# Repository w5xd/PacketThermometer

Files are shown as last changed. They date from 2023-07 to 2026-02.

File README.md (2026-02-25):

This repository documents a wireless thermometer project. 
Included are: a circuit design using Arduiono, a PCB design for the Arduino Pro Mini, an Arduino sketch. And an outdoor 3D printed enclosure.

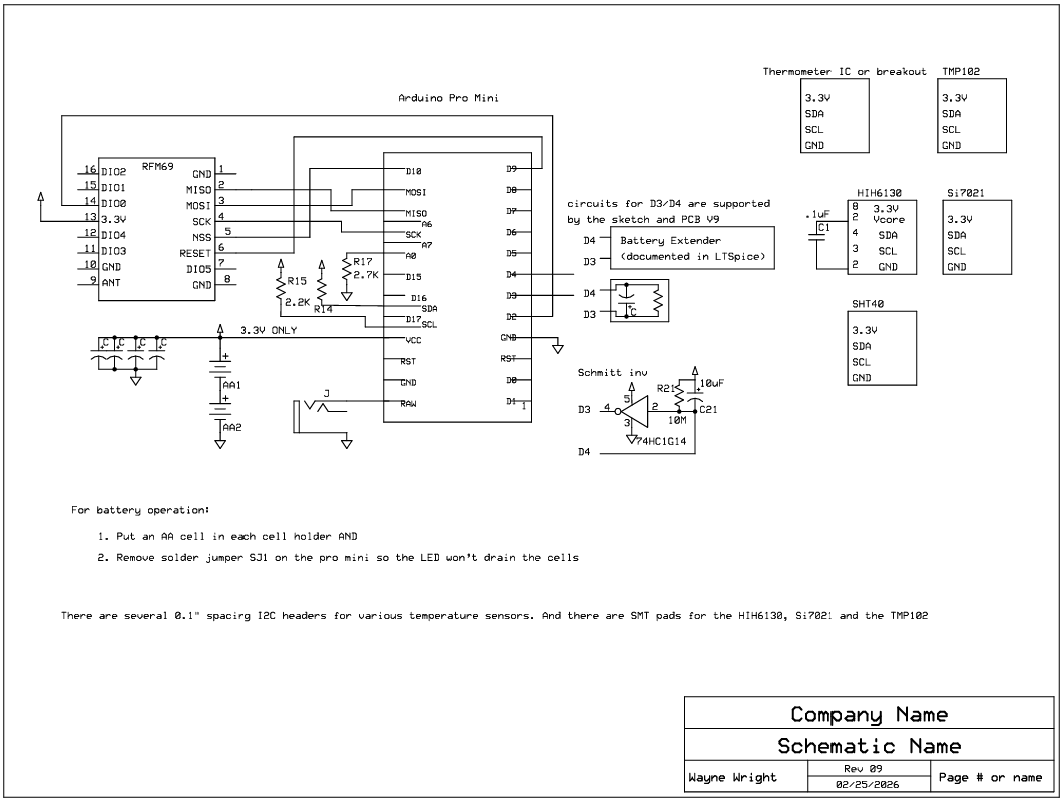
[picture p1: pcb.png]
<p align='center'></p>

The hardware configuration is the combination of the RFM69 wireless module
(<a href='https://learn.sparkfun.com/tutorials/rfm69hcw-hookup-guide'>https://learn.sparkfun.com/tutorials/rfm69hcw-hookup-guide</a>)
and any of several temperature and humidity sensors listed here.
The sensor positions on the PCB are:
<ul>

<li>TMP102. Its SMD board layout puts it at i2c address 0x49.
<li>There are headers  on the PCB for various break out temperature sensors.
The pin hookups are the same for any sensor: GND, VCC (3.3V), SDA, SCL are required.
The pin positions on the various Sparkfun breakout boards differ, which
is why there are several hole patterns on the PCB for headers</li><a href='https://learn.sparkfun.com/tutorials/tmp102-digital-temperature-sensor-hookup-guide'>https://learn.sparkfun.com/tutorials/tmp102-digital-temperature-sensor-hookup-guide.</a>
<li>HIH6131, measures humidity as well as temperature. The PCB layout puts it at i2c 0x27.
<a href='https://www.sparkfun.com/products/11295'>HIH6130</a>
has humidity in addition to temperature, but is limited to -20C to 85C.</li>
<li>Si7021, measures humidity and temperature. It is fixed at i2c 
address 0x40. It has a rather coarse temperature readout--about 1 degree Farenheit resolution
when set to its default 14 bit temperature digitization.
<li>SHT40. measures humdity and temperature. Address 0x44.
<li>TMP175. Temperature only. PCB leaves all address pins floating, therefore its i2c address is 0x37.

</ul>
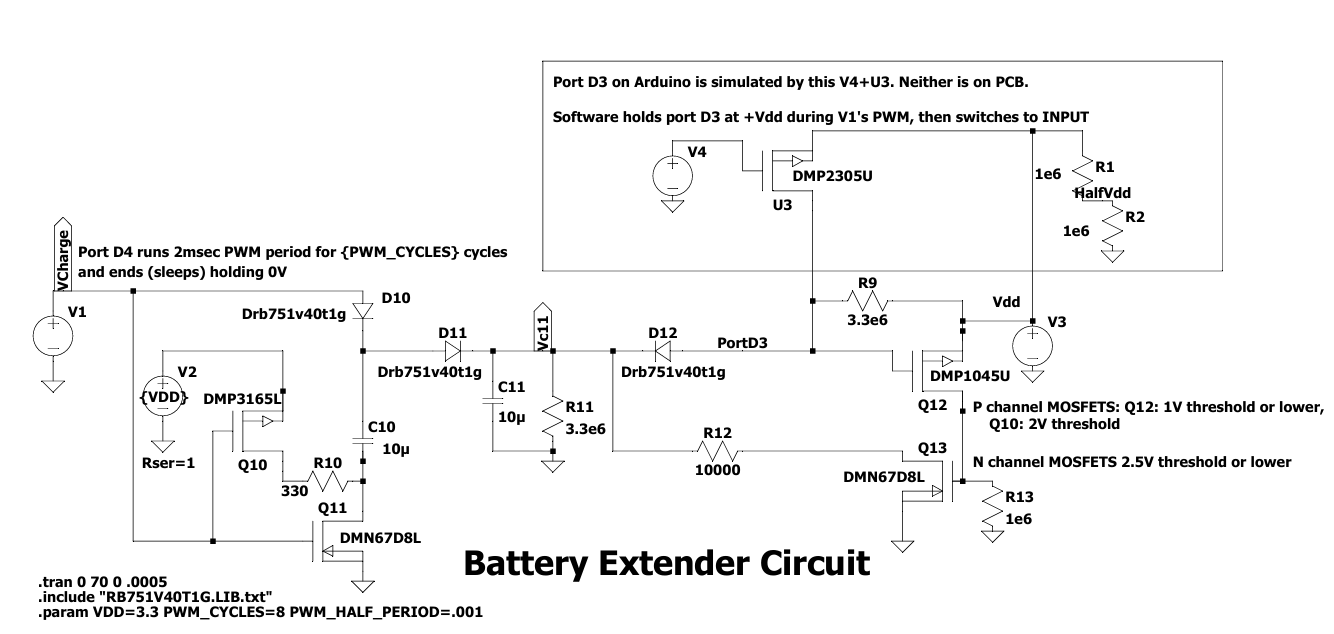
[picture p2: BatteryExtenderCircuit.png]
BatteryExtenderCircuit
<p align='center'></p>

Battery Extender

Three different circuits for implementing the long sleep time have been implemented. The original design, implemented
on PCB05 and earlier, is simply a parallel RC on the INT pin (D3 on the Arduino). Those components can be
chosen for an RC delay of as much as 100 seconds (10M times 10uF). That slow moving input stays close to
Vcc/2 for an extended period, which in turn causes the Atmega328 to draw up to about 
500uA above its minimal
sleep current for an extended length of time (See the Atmega328P specifications.) PCB06 places an inverting 74HC1G14 schmitt trigger 
to handle the slow-moving RC input. It has a lower current draw near Vcc/2, peaking below 300 uA.
PCB8 implements the MOSFET Battery Extender. PCB9 has PCB placements for all the above. The sketch
must be compiled for the hardware on the PCB, of course. And there is an option in the ino file for "none of the above"
which uses the CPU's Timer2 circuit and constant current draw of about 200uA.

The logic family of the schmitt trigger is important. The
74AHC1G14 draws about triple the current of the 74HC1G14 per their datasheets regarding slow moving inputs through Vcc/2. 
See the file <code>power&nbsp;supply&nbsp;current&nbsp;during&nbsp;RC&nbsp;decay.pdf</code> for actual measurements on a PCB version 6 with the CPU and TMP175 but
no RFM69.

REV08 and later have the Battery Extender Circuit. 
The Battery Extender eliminates the long period of excess current draw by 
accelerating the decay through Vcc/2. The circuit depends on a 
p-channel MOSFET with a low
gate threshold. The nominal threshold of the specified DMP1045U part
is -700mV, well outside of -Vcc/2. That MOSFET, Q12, turns on when the RC circuit at C11, R11 discharges that far
below Vcc. This in turn activates Q13 to quickly truncate the R11/C11 decay through R12, which then
crosses Vcc/2 in a few milliseconds. The other pair of MOSFETs, Q10 and Q11, implements a charge pump so that the
RC circuit discharges from as much as double Vcc (about 6V) to get a much longer time 
delay than is feasible without it.
The capacitors in the Battery Extender circuit can be identical, but must be ceramic 
(for very low leakage current compared to polarized capacitors.) Here is the modeled 
voltage at pin D3 from the LTSpice model.

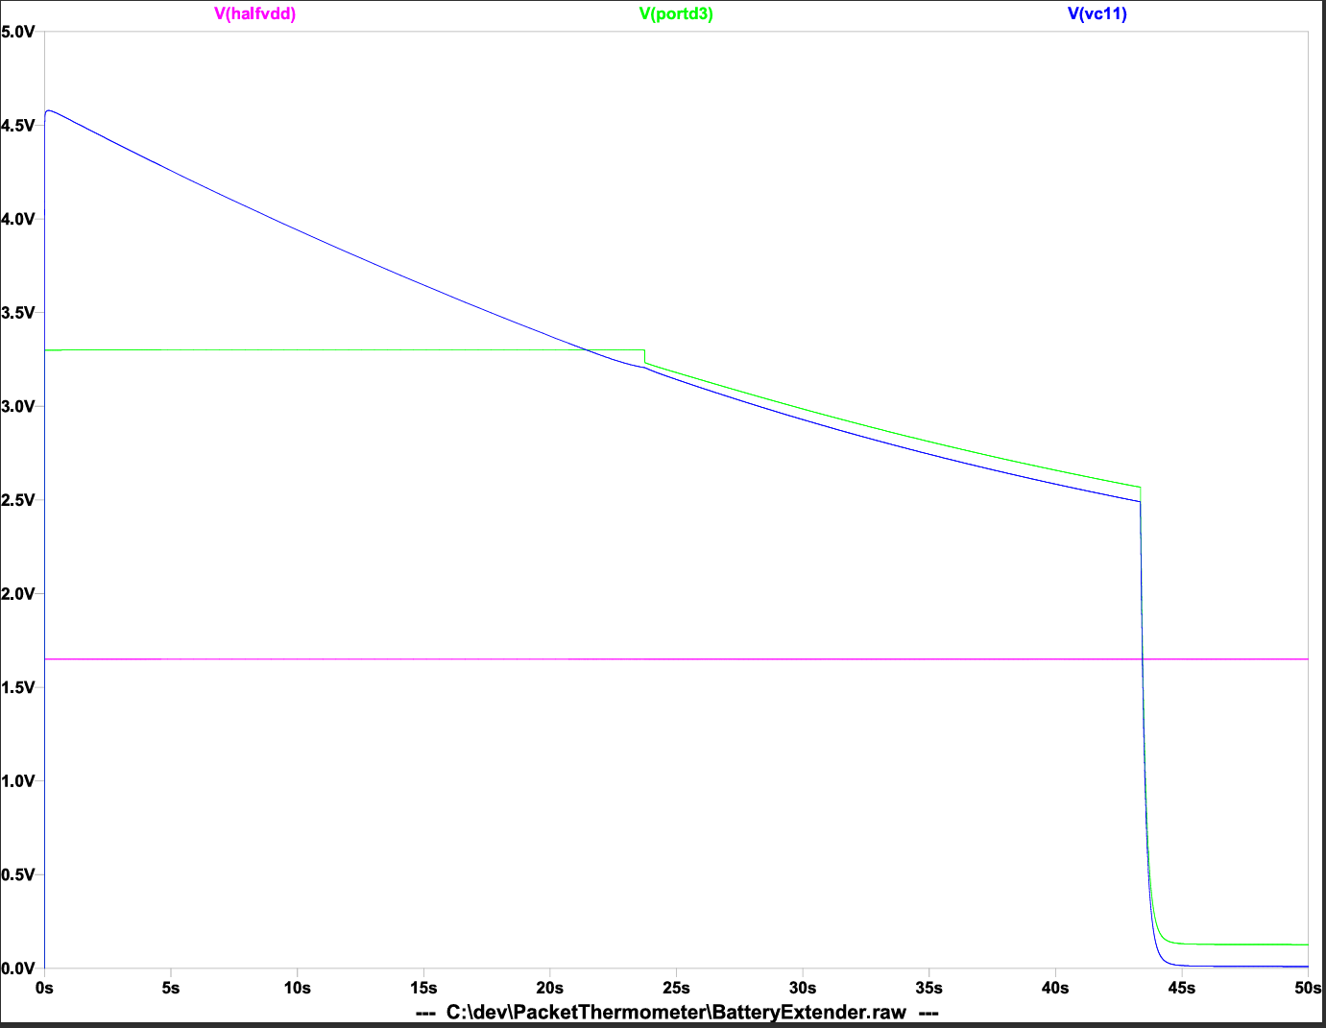
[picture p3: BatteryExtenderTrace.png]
BatteryExtenderTrace
<p align='center'></p>

Later PCB versions can be reverted to the REV05 single R and C timer by omitting all the Battery Extender components
except for  R11 and C11, along with installing a jumper in the holes provided at D12. The
appropriate #define in the ino file for REV05 must be uploaded.

PCB assembly

The parts list for building the PCB, including the Battery Extender: 
<a href='https://www.mouser.com/Tools/Project/Share?AccessID=548d5f9ecc'>
https://www.mouser.com/Tools/Project/Share?AccessID=548d5f9ecc</a>. The headers and battery holders,
and any hardware needed to mount in an enclosure are also needed.

|Quan|Item|Value|Form|
|:-|:-|:-|:-|
4|C1, C2, C3, C5|0.1µF|EIA 1206|
|3|C10, C11, C21|10µF|EIA 0805|
|1|C4|10µF|EIA 1206|
|3|D10, D11, D12|DRB751V40T1G||
|2|HIH6131, TMP175|SO8||
|1|J15|2.1 mm barrel jack PJ-202A|for power plug|
|1|Q10|DMP3165l|SOT23-3|
|2|Q11, Q13|DMN67D8L|SOT23-3|
|1|Q12|DMP1045U|SOT23-3|
|2|R9, R11|3.3M|EIA 0805|
|1|R10|330|EIA 0805|
|1|R12|10K|EIA 0805|
|1|R13|1M|EIA 0805|
|2|R14, R15|2.2K|EIA 0805|
|1|R17|2.7K|EIA 1206|
|1|R21|10M|EIA 0805|

Only one of the battery saver circuit, or the 74HC1G14 time delay circuit, can be installed.<br/>
The battery saver is R9-R13, D10-D12, Q10-Q12, C10 and C11.<br/>
The 74HC1G14 needs R21 and C21.<br/><br/>

While the PCB has multiple positions for placing temperature sensors, the sketch reports temperature
from just one of them per the #define in the ino file.
I had success baking the SMD circuits with tight clearances using the technique in this
<a href='https://www.youtube.com/watch?v=xPFujTJbUkI'>video</a>.
The Battery Extender circuit is positioned under the Pro Mini, which makes it impossible to test
if the Arduino is in place. If you are going to install the assembled PCB in the 3D printed
weather tight enclosure, the assembly only fits if you solder the Pro Mini in place with, at most,
0.100 inch headers between the Arduino and the PCB. That is, you must test the Battery Extender
before soldering the Pro Mini in place. This order of assembly is <i>required</i> for that case
of installing this PCB in the 3D printed enclosure:
<ol>
<li>Prepare an Arduino with headers that can be jumped to headers on the PCB at the Arduino
position. A 5V Arduino (like an Uno or Mega) can be used in this test step, but then you <b><i>must</i></b> omit
all the 3.3 volt parts in the following SMD baking step!
<li>Bake all the Battery Extender SMD components onto the PCB. 
<li>Install headers on the PCB that will eventually be used to mount the 3.3V Pro Mini.
<li>Upload the WirelessThermometer.ino sketch with appropriate #define's set onto the
test Arduino.
<li>Jumper the following pins between the two boards:
<ol>
<li>Ground
<li>RAW (3.3V or 5.0V)
<li>D3
<li>D4
</ol>
<li>At this point the thermometer should successfully sleep according to the parameter SetD4PwmCount.
Set to zero, it should sleep for about 7 or 8 seconds.
SetD4PwmCount up to 255 should sleep for more than 65 seconds.
<li>If you baked a temperature sensor, it should also be printed out on the Serial port.
<li>Once the Battery Extender circuit works as predicted, the remaing top side PCB components should be
mounted <i>except</i> the Pro Mini
<li>Solder the AA cell holder(s) to the PCB bottom. In REV08 of the PCB and later, and using
the Keystone 2462 double AA holder, these last two items can be in either order.
Otherwise, you had better solder the Pro Mini last.
<li>Finally, the Pro Mini may be soldered onto the headers installed in step (3) above.
</ol>

Power options
<ul>
<li>The circuit is simple and can be haywired without a PCB. 
<li>The PCB has positions for two AA cells. It has hole configurations for
cell holders. Either a two-cell keystone 2462 holder or two one-cell keystone 2460 
holders fit. In PCB REV08 and later, the 2462 fits in either of two orientations that are 180 degrees rotated.
<li>On the Arduinio Mini Pro, 3.3V version, remove solder jumper SJ1 to disable
the on-board volatage regulator and, especially, the power drain from its LED. 
<li>Or, a PJ-202A 5.5mm x 2.1mm power jack may be installed on the PCB, which routes up to 12VDC
to the regulator on the Pro Mini. The PCB has holes to accommodate the jack on either
the PCB's top or bottom.
</ul>

SMD components of size 1206 and 0805 are easy enough to solder by hand. 
A pair of AAA lithium cells
powered one of these for 9 months (and counting) with SetDelayLoopCount 
configured such that updates occur about every 11 minutes. A different unit
configured for 5 minute updates lasted 6 months. AA cells are rated
to about twice the Amp-Hour life of the equivalent chemistry AAA cells.

A 2.7K resistor is from A0 to ground for the purpose of telemetering the battery volatage. 

The system is powered with the 2 cell battery wired to VCC (not RAW).

The required SetFrequencyBand settings are documented in RFM69.h (91 in USA). The Arduino
can be programmed through either its serial interface or the ISP pins on the PCB. But
the RFM69 configuration can only be accomplished through the Arduino's serial interface. 

Cover

The CAD directory has a 3D model for a one-piece enclosure that covers the arduino, but leaves the
battery pack exposed. And there is also a 3D model for weather tight O-Ring enclosure that 
mates the PCB holes.

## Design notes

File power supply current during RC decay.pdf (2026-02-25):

Sheet1

Power supply current measurements

Time (s) | 74AHC1G14 | 74HC1G14
10 | 0 | 0
20 | 0.2 | 10
30 | 22 | 40
40 | 80 | 85
50 | 160 | 132
60 | 240 | 180
70 | 325 | 220
80 | 420 | 260
90 | 500
100 | 570
110 | 630

uA

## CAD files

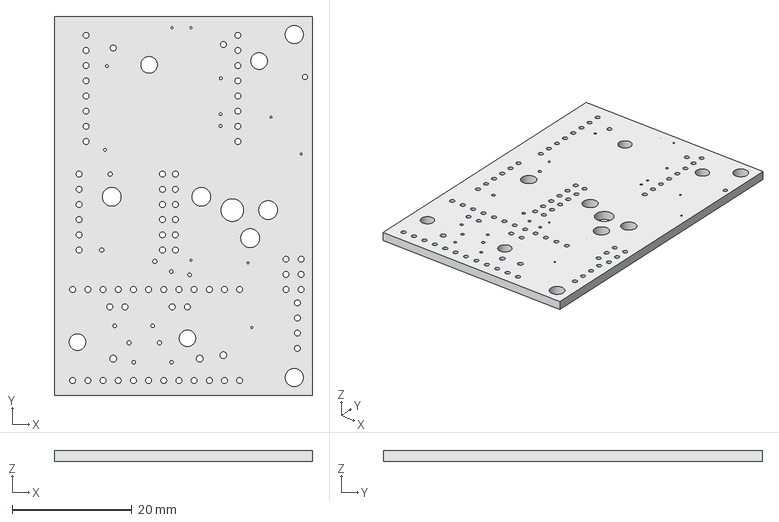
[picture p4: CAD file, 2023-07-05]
CAD/pcb-packet-thermometer.step
43.2 x 63.5 x 1.78 mm

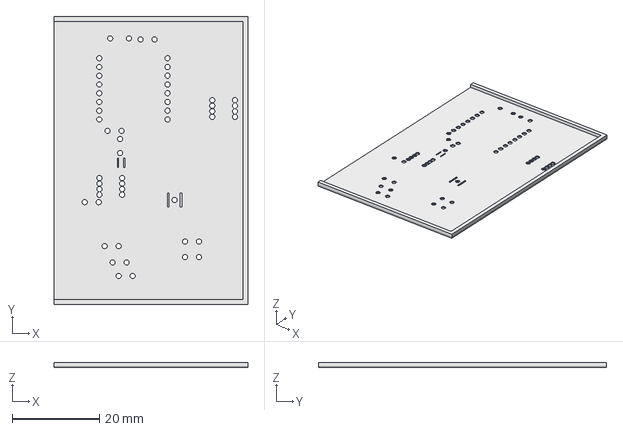
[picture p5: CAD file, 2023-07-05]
CAD/pcb-packet-thermometer-mask.step
44.4 x 65.9 x 1.20 mm

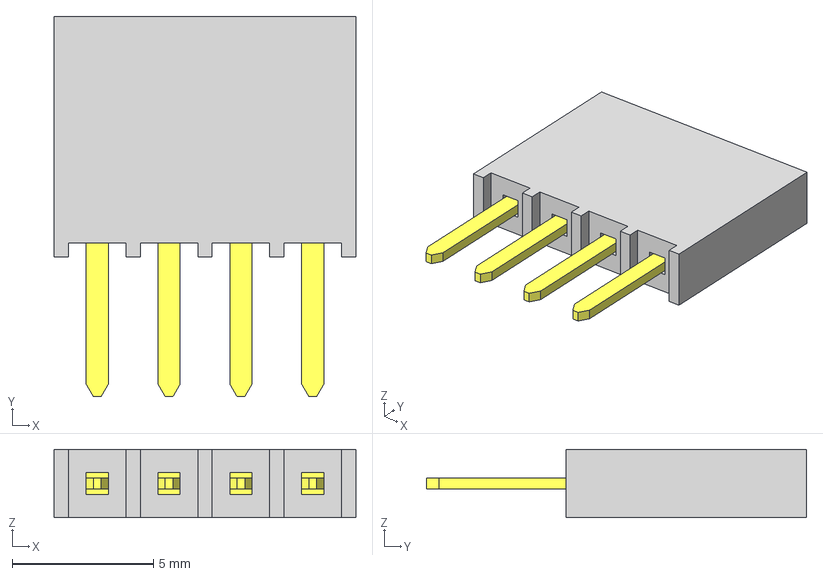
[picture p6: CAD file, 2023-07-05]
CAD/SSW-104-02-T-S.stp
10.7 x 13.4 x 2.41 mm
P2SSW-104-02-T-S
T1SSW-104-02-T-S

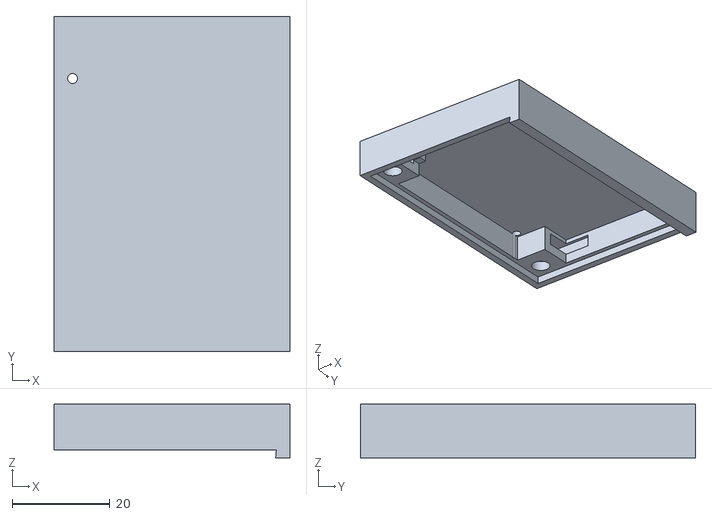
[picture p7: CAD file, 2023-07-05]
CAD/cover.stl
48.3 x 68.6 x 11.0

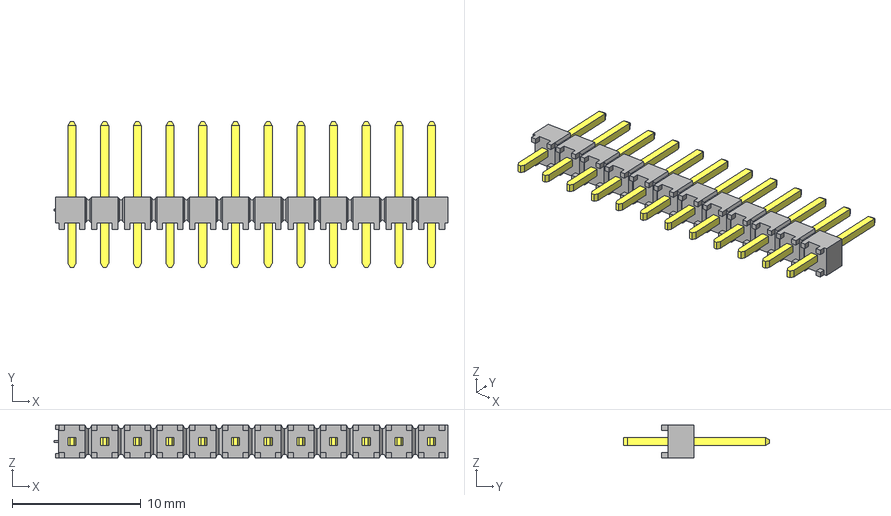
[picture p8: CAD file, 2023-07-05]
CAD/TSW-112-23-T-S.stp
30.6 x 11.3 x 2.54 mm
T-1S6-16-TSW-1-23-12-S
TSW-112-23-T-S_body

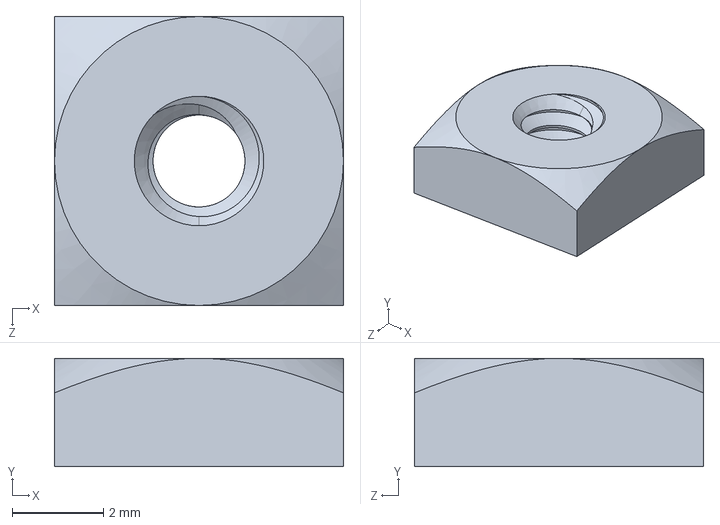
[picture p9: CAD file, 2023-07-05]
CAD/94785A511_18-8 Stainless Steel Square Nut.STEP
6.35 x 2.38 x 6.35 mm

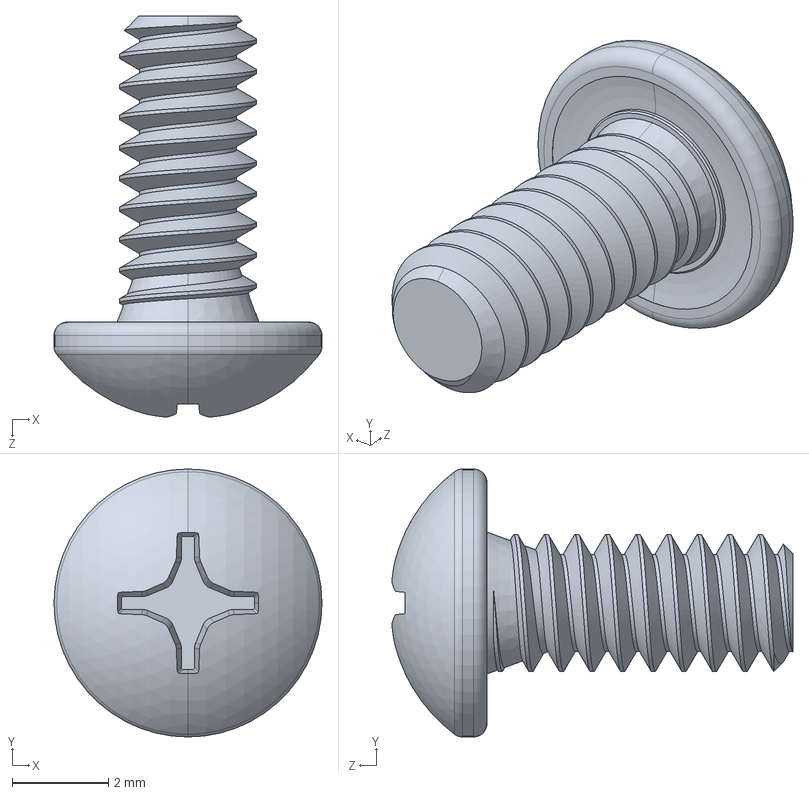
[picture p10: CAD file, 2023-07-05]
CAD/91772A106_Passivated 18-8 Stainless Steel Pan Head Phillips Screw.STEP
5.56 x 5.56 x 8.32 mm

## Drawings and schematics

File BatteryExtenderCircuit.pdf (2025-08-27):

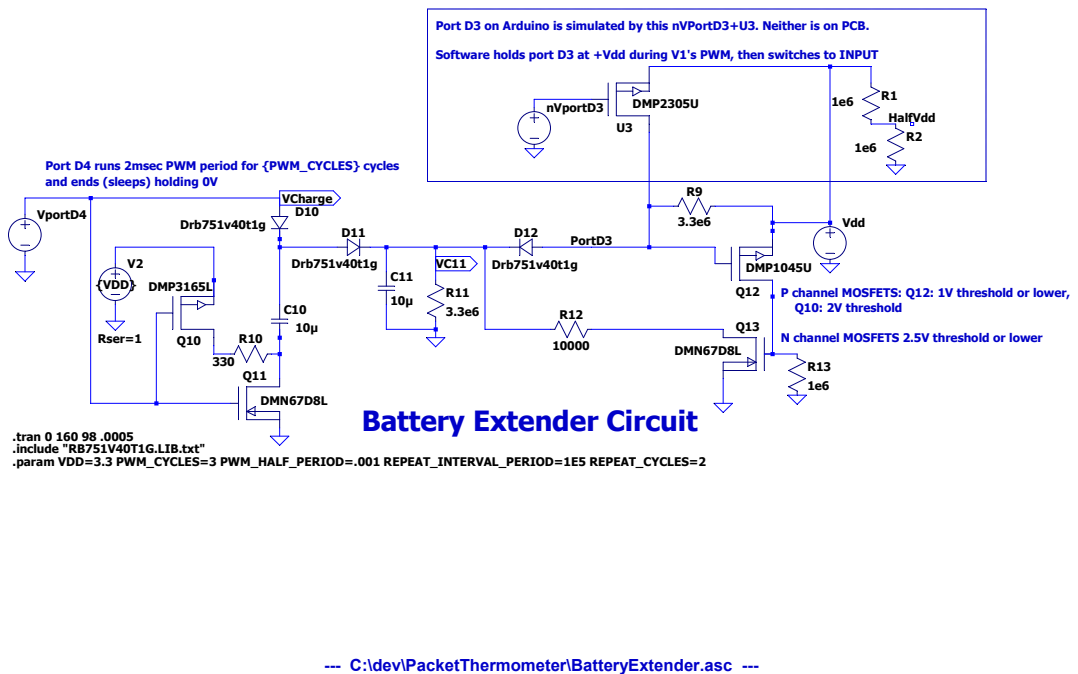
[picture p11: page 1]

Port D3 on Arduino is simulated by this nVPortD3+U3. Neither is on PCB.

Software holds port D3 at +Vdd during V1's PWM, then switches to INPUT

Port D4 runs 2msec PWM period for {PWM_CYCLES} cycles
and ends (sleeps) holding 0V

P channel MOSFETS: Q12: 1V threshold or lower,
Q10: 2V threshold

N channel MOSFETS 2.5V threshold or lower

--- C:\dev\PacketThermometer\BatteryExtender.asc ---

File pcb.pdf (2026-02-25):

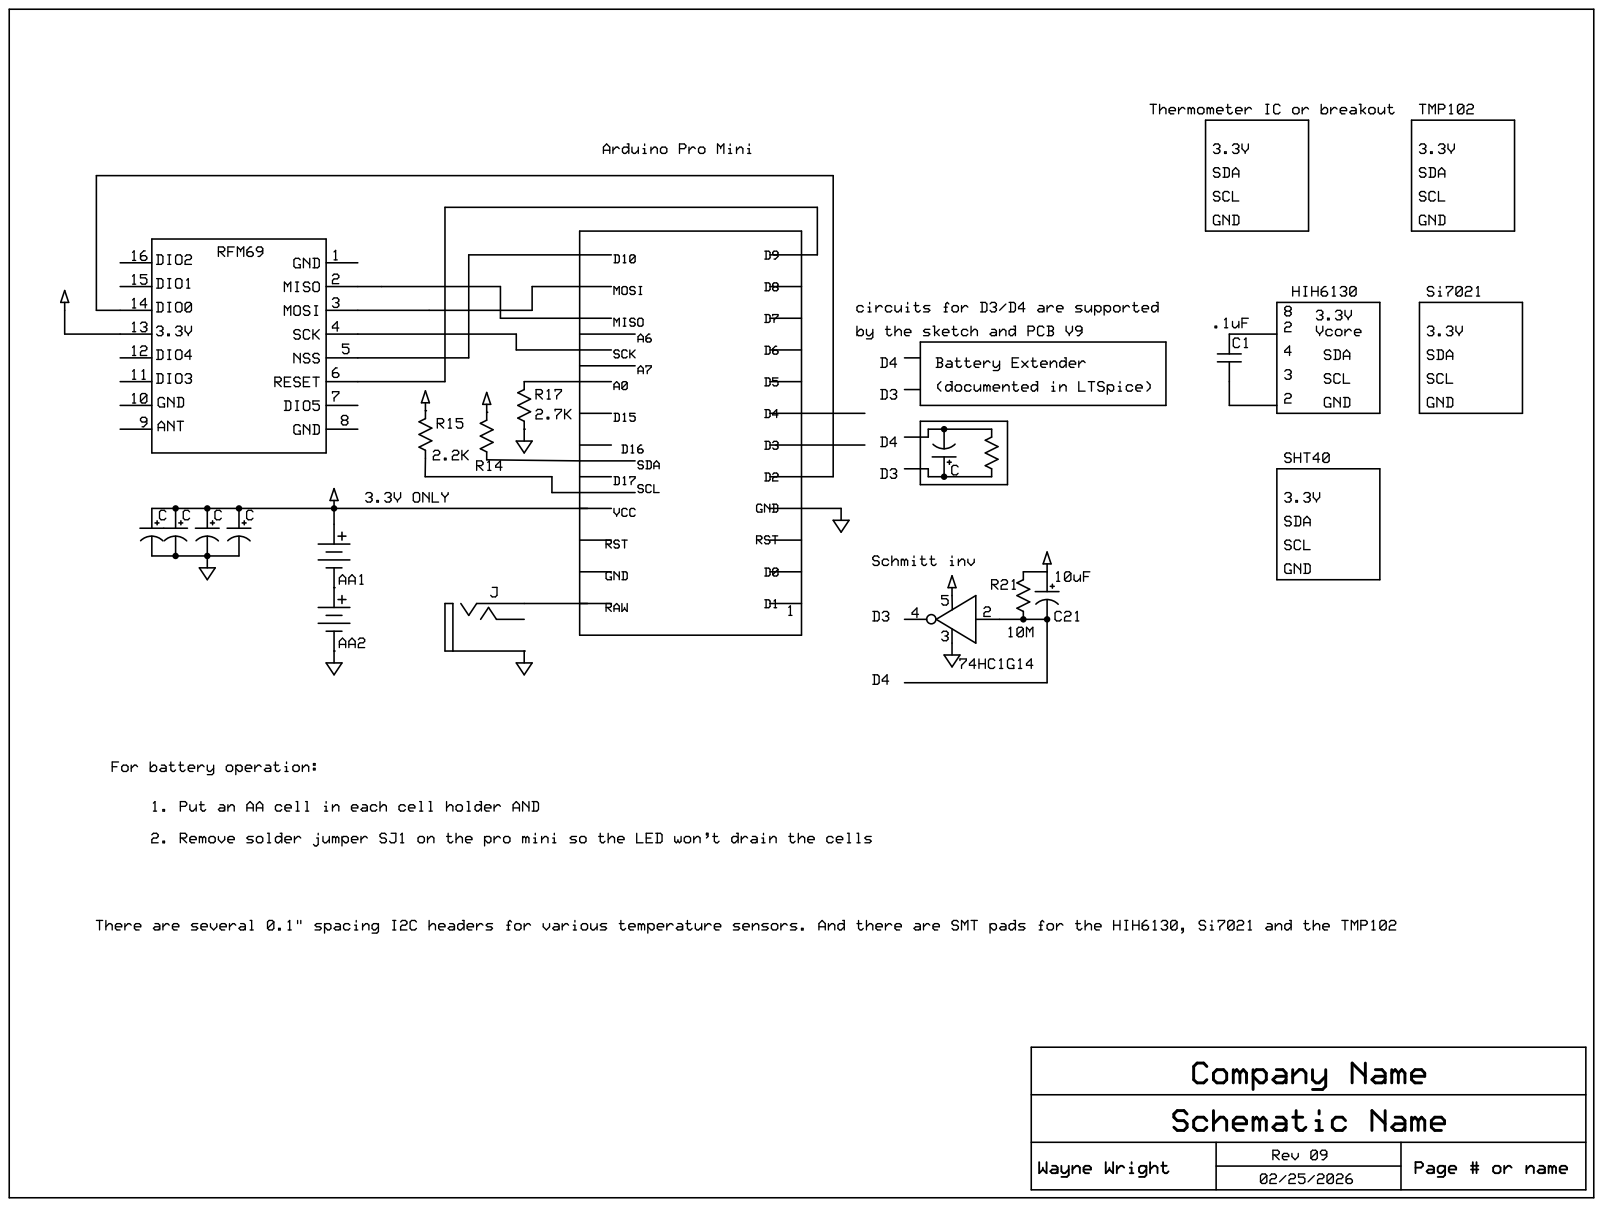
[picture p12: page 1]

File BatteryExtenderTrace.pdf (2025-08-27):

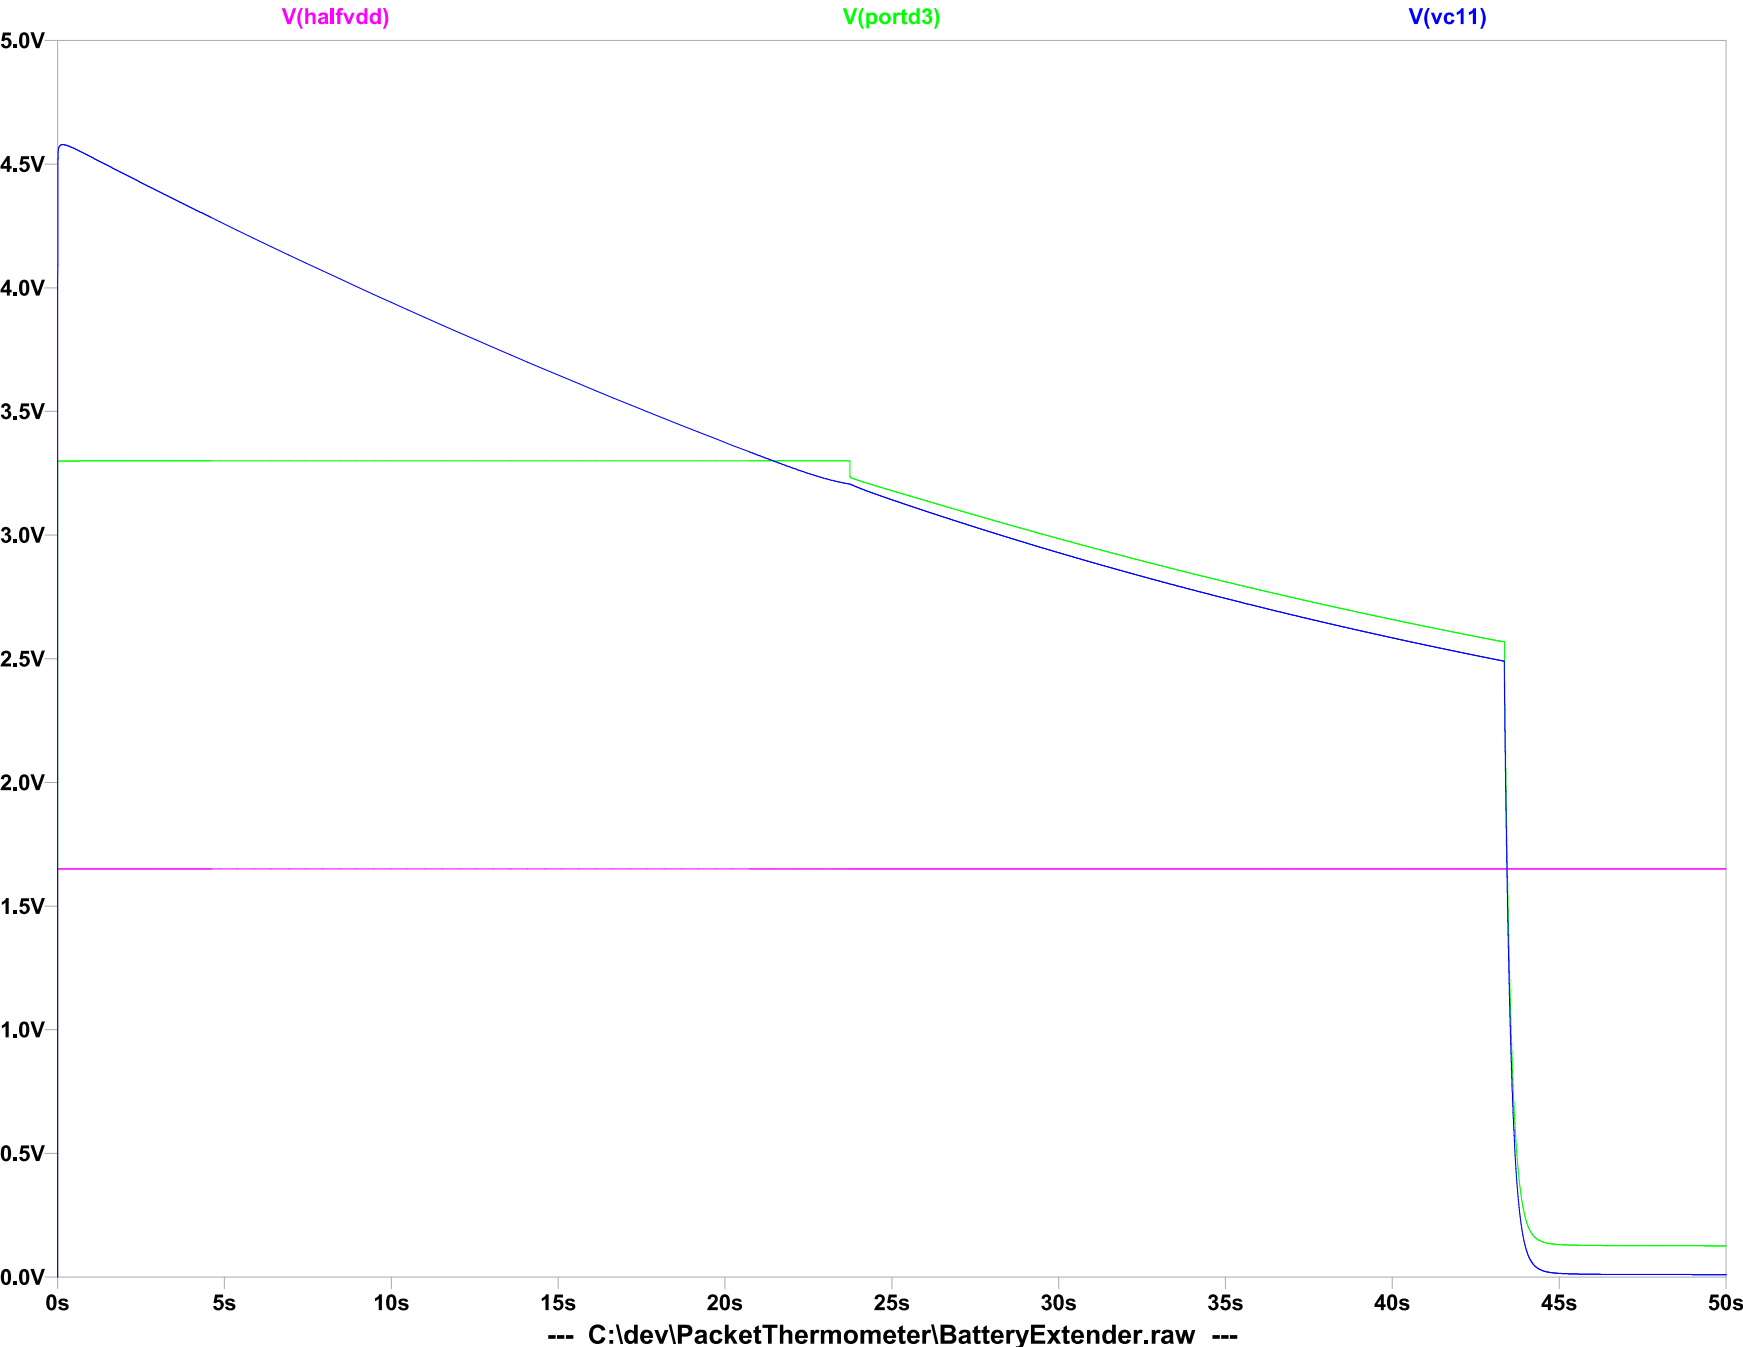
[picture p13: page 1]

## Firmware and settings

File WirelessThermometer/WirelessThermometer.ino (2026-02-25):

/* This sketch is for an Arduino wired to
** a) RFM69 radio transceiver
** b) temperature sensor or combination temperature/humidity sensor
**
** This sketch is accompanied in its git repository by a design for a 1.7" by 2.5" PCB.
** That PCB makes the connections more convenient, and the packaging solid, but its
** also workable to simply use the sparkfun breakout packaging of the RFM69 and either
** the TMP102 or the Si7021 and haywire the three together with a 2 cell battery.
**
** This sketch has compile time #define's for the various i2c sensors. While multiple
** sensors can be compiled in, the #define's in this sketch arrange for only one of the
** sensor readings to be telemetered.
*/

#include <RadioConfiguration.h>
#include <SPI.h>
#include <EEPROM.h>
#include <avr/sleep.h>
#include <avr/interrupt.h>
#include <avr/power.h>

// SparkFun's part numbers are:
// 915MHz: https://www.sparkfun.com/products/12775 (or to SMD mount: https://www.sparkfun.com/products/13909)
// 434MHz: https://www.sparkfun.com/products/12823 (SMD part: https://www.sparkfun.com/products/13910)

// Parts of the code in this sketch are taken from these sparkfun pages,
// as are all the wiring instructions:
// https://learn.sparkfun.com/tutorials/rfm69hcw-hookup-guide

// Uses the RFM69 library by Felix Rusu, LowPowerLab.com
// Original library: https://github.com/LowPowerLab/RFM69

// code only supports reporting any one of TMP102 HIH6130 TMP175 SI7021
// except: SI7021 can also be paired with TMP sensor
//#define USE_TMP102_PCB
//#define USE_TMP102_BREAKOUT
//#define USE_HIH6130
#define USE_TMP175
//#define USE_SI7021
//#define USE_SHT41

#if defined(USE_TMP102_PCB) || defined(USE_TMP102_BREAKOUT)
#define USE_TMP102
#endif

// The TMP102 has temperature only, -40C to 100C
// The HIH6130 has temperature and relative humidity, -20C to 85C

// Include the RFM69 and SPI libraries:
#define USE_RFM69
#define USE_SERIAL
//if a permanent power source is connected, comment out the next line...
#define TELEMETER_BATTERY_V // ...because the power supply voltage wont ever change.

#define TIMER_INIT_STYLE_REV05 5    // REV05 of PCB and earlier. R and C across D3 and D4
#define TIMER_INIT_STYLE_REV06 6  // REV06 of PCB. with 74HC1G14 Schmitt trigger. 
#define TIMER_INIT_STYLE_REV07 7    // REV07+ PCB have battery extender: D3 and D4 charge pump
// PCB rev 9 can be populated as any of the above

#define TIMER_INIT_STYLE TIMER_INIT_STYLE_REV07 // One of the above
/* REV09 of the PCB has component positions for ANY of the above configurations.
** Build this sketch for the way your board is actually populated*/

// Using TIMER2 to sleep costs about 200uA continuous of sleep-time current, but saves the 1uF/10Mohm external parts
//#define SLEEP_WITH_TIMER2

#if defined(USE_RFM69)
#include <RFM69.h>
#endif

#include <Wire.h>

#if defined(USE_HIH6130)
#include "HIH6130Helper.h"
#endif
#if defined(USE_TMP175) || defined(USE_TMP102)
#include "Tmp175.h"
#endif
#if defined(USE_SI7021)
#include "Si7021.h"
#endif
#if defined(USE_SHT41)
#include "Sht41.h"
#endif

#define VERSION_STRING "REV 16"

namespace {
    const int BATTERY_PIN = A0; // digitize (fraction of) battery voltage
    const int TIMER_RC_GROUND_PIN = 4;
    const int TIMER_RC_PIN = 3; // sleep uProc using RC circuit on this pin

    const unsigned long FirstListenAfterTransmitMsec = 20000;// at system reset, listen Serial/RF for this long
    const unsigned long NormalListenAfterTransmit = 300;// after TX, go to RX for this long

    const float MAX_VALID_TEMPERATURE_C = 80.f;

#if defined(USE_TMP102_PCB) // The TMP102 is documented to be backwards compatible with TMP75 i2c commands.
    TMP175 tmp102(0x49, 30); /* PCB layout puts tmp102 at 0x49.*/
#elif defined(USE_TMP102_BREAKOUT)
    TMP175 tmp102(0x48, 30); /* TMP102 breakout board gives 0x48*/
#endif
#if defined(USE_HIH6130)
    HomeAutomationTools::HIH6130 sensor0;
#endif
#if defined(USE_TMP175)
    TMP175 tmp175(0x37); /* PCB layout puts tmp175 at 0x37*/
#endif
#if defined(USE_SI7021)
    SI7021 si7021;
#endif
#if defined(USE_SHT41)
    SHT41 sht41;
#endif

#if defined(USE_RFM69)
// AES encryption (or not):
    const bool ENCRYPT = true; // Set to "true" to use encryption
    // Use ACKnowledge when sending messages (or not):
    const bool USEACK = true; // Request ACKs or not
    const int RFM69_RESET_PIN = 9;
    const int RFM69_CHIP_SELECT_PIN = 10;
    const int RFM69_INT_PIN = 2;
 
    // Create a library object for our RFM69HCW module:
    RFM69 radio(RFM69_CHIP_SELECT_PIN, RFM69_INT_PIN, true);
#endif

#if defined(TELEMETER_BATTERY_V)
    void ResetAnalogReference();
#endif

    RadioConfiguration radioConfiguration;
    bool enableRadio = false;
    unsigned long TimeOfWakeup;
    const unsigned MAX_SLEEP_LOOP_COUNT = 5000; // a couple times per day is minimum check-in interval
    unsigned SleepLoopTimerCount = 30; // approx 10 seconds per Count
    uint8_t GatewayNodeId = 1;
    uint8_t D4PwmCount = 100; // range is 0 to 255
    enum EepromAddress_t {SLEEP_TIMER_COUNT_OFFSET = RadioConfiguration::TOTAL_EEPROM_USED,
            GATEWAY_NODEID_OFFSET = SLEEP_TIMER_COUNT_OFFSET + sizeof(SleepLoopTimerCount),
            D4PWMCOUNT = GATEWAY_NODEID_OFFSET + sizeof(GatewayNodeId),
            THERMOMETER_EEPROM_USED = D4PWMCOUNT + sizeof(D4PwmCount)};
}

void setup()
{
#if defined(USE_SERIAL)
    // Open a serial port so we can send keystrokes to the module:

    Serial.begin(9600);

#if defined(USE_SI7021)
    Serial.println("PacketThermometer " VERSION_STRING " SI7021");
#endif
#if defined(USE_TMP102)
    Serial.println("PacketThermometer " VERSION_STRING " TMP102");
#endif
#if defined(USE_HIH6130)
    Serial.println("PacketThermometer " VERSION_STRING " HIH6130");
#endif
#if defined(USE_TMP175)
    Serial.println("PacketThermometer " VERSION_STRING " TMP175");
#endif
#if defined(USE_SHT41)
    Serial.println("PacketThermometer " VERSION_STRING " SHT41");
#endif
#if TIMER_INIT_STYLE <= TIMER_INIT_STYLE_REV05
    Serial.println(F("TIMER INIT R AND C"));
#elif TIMER_INIT_STYLE == TIMER_INIT_STYLE_REV06
    Serial.println(F("TIMER INIT IS PCB REV06 ONLY"));
#elif TIMER_INIT_STYLE >= TIMER_INIT_STYLE_REV07
   Serial.println(F("TIMER INIT IS CHARGE PUMP"));
#endif

    Serial.print("Node ");
    Serial.print(radioConfiguration.NodeId(), DEC);
    Serial.print(" on network ");
    Serial.print(radioConfiguration.NetworkId(), DEC);
    Serial.print(" band ");
    Serial.print(radioConfiguration.FrequencyBandId(), DEC);
    Serial.print(" key ");
    radioConfiguration.printEncryptionKey(Serial);
    Serial.println(" ready");
#endif

    Wire.begin();

#if defined(USE_TMP102)
    tmp102.startReadTemperature();
#endif
#if defined(USE_TMP175)
    tmp175.startReadTemperature();
#endif
#if defined(USE_SI7021)
#endif
#if defined(USE_SHT41)
        sht41.startReadTemperature();
#endif

#if defined(USE_RFM69)
    pinMode(RFM69_CHIP_SELECT_PIN, OUTPUT);
    digitalWrite(RFM69_CHIP_SELECT_PIN, HIGH);
    SPI.begin();

    // Initialize the RFM69HCW:
    auto nodeId = radioConfiguration.NodeId();
    auto networkId = radioConfiguration.NetworkId();
    auto fbId = radioConfiguration.FrequencyBandId();
    auto ok = nodeId != 0xff &&
        networkId != 0xff &&
        fbId != 0xff &&
        radio.initialize(fbId, nodeId, networkId);
#if defined(USE_SERIAL)
    Serial.println(ok ? "Radio init OK" : "Radio init failed");
#endif
    if (ok)
    {
        enableRadio = true;
        uint32_t freq;
        bool haveFreq = radioConfiguration.FrequencyKHz(freq);
        radio.setHighPower(); // Always use this for RFM69HCW
        // Turn on encryption if desired:
        if (ENCRYPT)
            radio.encrypt(radioConfiguration.EncryptionKey());
        if (haveFreq)
        {
            auto setF = 1000 * freq;
            radio.setFrequency(setF);
        }
#if defined(USE_SERIAL)
        if (haveFreq)
            {Serial.print("Radio Config Freq="); Serial.println(freq);}
        Serial.print("Freq= "); Serial.print(radio.getFrequency() / 1000); Serial.println(" KHz");
#endif   
        EEPROM.get(GATEWAY_NODEID_OFFSET, GatewayNodeId);
        if (GatewayNodeId == 0xFFu)
            GatewayNodeId = 1;
#if defined(USE_SERIAL)
        Serial.print("Gateway Node ID:");
        Serial.println(static_cast<unsigned>(GatewayNodeId));
#endif
    }

#endif

    EEPROM.get(D4PWMCOUNT, D4PwmCount);

#if defined(TELEMETER_BATTERY_V)
    ResetAnalogReference();
#endif

    digitalWrite(TIMER_RC_GROUND_PIN, LOW);
    pinMode(TIMER_RC_GROUND_PIN, OUTPUT);

    TimeOfWakeup = millis(); // start loop timer now

    unsigned eepromLoopCount(0);
    EEPROM.get(SLEEP_TIMER_COUNT_OFFSET, eepromLoopCount);
    if (eepromLoopCount && eepromLoopCount <= MAX_SLEEP_LOOP_COUNT)
        SleepLoopTimerCount = eepromLoopCount;

#if defined(USE_SERIAL)
    Serial.print("SleepLoopTimerCount = ");
    Serial.println(SleepLoopTimerCount);
#if TIMER_INIT_STYLE >= TIMER_INIT_STYLE_REV07
    Serial.print("D4 PWM Count:");
    Serial.println(static_cast<unsigned>(D4PwmCount));
#endif
#endif

    Wire.end();
}

/* Power management:
 * For ListenAfterTransmitMsec we stay awake and listen on the radio and Serial.
 * Then we power down all: sensor, radio and CPU and CPU
 * sleep using SleepTilNextSample.
 */

namespace {
    unsigned SleepTilNextSample();

    unsigned long ListenAfterTransmitMsec = FirstListenAfterTransmitMsec;
    unsigned int sampleCount;

    bool processCommand(const char* pCmd)
    {
        static const char SET_LOOPCOUNT[] = "SetDelayLoopCount";
        static const char SET_GATEWAY[] = "SetGatewayNodeId";
        static const char SET_D4PWMCOUNT[] = "SetD4PwmCount";
        if (strncmp(pCmd, SET_LOOPCOUNT, sizeof(SET_LOOPCOUNT) - 1) == 0)
        {
            pCmd = RadioConfiguration::SkipWhiteSpace(
                pCmd + sizeof(SET_LOOPCOUNT) - 1);
            if (pCmd)
            {
                unsigned v = RadioConfiguration::toDecimalUnsigned(pCmd);
                // don't allow zero, nor more than MAX_SLEEP_LOOP_COUNT
                if (v && v < MAX_SLEEP_LOOP_COUNT)
                {
                    SleepLoopTimerCount = v;
                    EEPROM.put(SLEEP_TIMER_COUNT_OFFSET, SleepLoopTimerCount);
                    return true;
                }
            }
        }
        else if (strncmp(pCmd, SET_GATEWAY, sizeof(SET_GATEWAY) - 1) == 0)
        {
            pCmd = RadioConfiguration::SkipWhiteSpace(
                pCmd + sizeof(SET_GATEWAY) - 1);
            if (pCmd)
            {
                GatewayNodeId = static_cast<uint8_t>(RadioConfiguration::toDecimalUnsigned(pCmd));
                EEPROM.put(GATEWAY_NODEID_OFFSET, GatewayNodeId);
                return true;
            }
        }
        else if (strncmp(pCmd, SET_D4PWMCOUNT, sizeof(SET_D4PWMCOUNT) - 1) == 0)
        {
            pCmd = RadioConfiguration::SkipWhiteSpace(
                pCmd + sizeof(SET_D4PWMCOUNT) - 1);
            if (pCmd)
            {
                D4PwmCount = static_cast<uint8_t>(RadioConfiguration::toDecimalUnsigned(pCmd));
                EEPROM.put(D4PWMCOUNT, D4PwmCount);
                return true;
            }
        }        
        return false;
    }
}

void loop()
{
    unsigned long now = millis();

#if defined(USE_SERIAL)
    // Set up a "buffer" for characters that we'll send:
    static char sendbuffer[62];
    static int sendlength = 0;
    // In this section, we'll gather serial characters and
    // send them to the other node if we (1) get a carriage return,
    // or (2) the buffer is full (61 characters).

    // If there is any serial input, add it to the buffer:

    if (Serial.available() > 0)
    {
        TimeOfWakeup = now; // extend timer while we hear something
        char input = Serial.read();

        if (input != '\r') // not a carriage return
        {
            sendbuffer[sendlength] = input;
            sendlength++;
        }

        // If the input is a carriage return, or the buffer is full:
        bool eol = (input == '\r') || (input == '\n');

        if (eol || (sendlength == sizeof(sendbuffer) - 1)) // CR or buffer full
        {
            sendbuffer[sendlength] = 0;
            if (processCommand(sendbuffer))
            {
                Serial.print(sendbuffer);
                Serial.println(" command accepted for thermometer");
            }
            else if (radioConfiguration.ApplyCommand(sendbuffer))
            {
                Serial.print(sendbuffer);
                Serial.println(" command accepted for radio");
            }
            Serial.println("ready");
            sendlength = 0; // reset the packet
        }
    }
#endif

#if defined(USE_RFM69) 
    // RECEIVING
    // In this section, we'll check with the RFM69HCW to see
    // if it has received any packets:

    if (enableRadio && radio.receiveDone()) // Got one!
    {
        // Print out the information:
        TimeOfWakeup = now; // extend sleep timer
#if defined(USE_SERIAL)
        Serial.print("received from node ");
        Serial.print(radio.SENDERID, DEC);
        Serial.print(", message [");

        // The actual message is contained in the DATA array,
        // and is DATALEN bytes in size:

        for (byte i = 0; i < radio.DATALEN; i++)
            Serial.print((char)radio.DATA[i]);

        // RSSI is the "Receive Signal Strength Indicator",
        // smaller numbers mean higher power.

        Serial.print("], RSSI ");
        Serial.println(radio.RSSI);
#endif
        // RFM69 ensures trailing zero byte, unless buffer is full...so
        radio.DATA[sizeof(radio.DATA) - 1] = 0; // ...if buffer is full, ignore last byte
        if (processCommand((const char*)&radio.DATA[0]))
        {
#if defined(USE_SERIAL)
            Serial.println("Received command accepted");
#endif
        }
        if (radio.ACKRequested())
        {
            radio.sendACK();
#if defined(USE_SERIAL)
            Serial.println("ACK sent");
#endif
        }
    }
#endif

    static bool SampledSinceSleep = false;
    if (!SampledSinceSleep)
    {
        static char buf[64];
        SampledSinceSleep = true;
        int batt(0);
#if defined(TELEMETER_BATTERY_V)
        // 10K to VCC and (wired on board) 2.7K to ground
        pinMode(BATTERY_PIN, INPUT_PULLUP); // sample the battery
        batt = analogRead(BATTERY_PIN);
        pinMode(BATTERY_PIN, INPUT); // turn off battery drain
#endif

        Wire.begin();

#if (defined(USE_TMP102) || defined(USE_TMP175)) && !defined(USE_SI7021) && !defined(USE_SHT41)
        {
#if defined(USE_TMP102)
            auto temperature256 = tmp102.finishReadTempCx256();
#elif defined(USE_TMP175)
            auto temperature256 = tmp175.finishReadTempCx256();
#endif
            char sign = '+';
            if (temperature256 < 0) {
                temperature256 = -temperature256;
                sign = '-';
            }
            else if (temperature256 == 0)
                sign = ' ';

            int whole = temperature256 >> 8;
            if (whole >= static_cast<int>(MAX_VALID_TEMPERATURE_C))
                sign = sign == '-' ? '<' : '>';
            int frac = temperature256 & 0xFF;
            frac *= 100;
            frac >>= 7; // range of 0 through 199
            frac += 5; // round up (away from zero)
            if (frac >= 200)
            {
                whole += 1; // carry
                frac = 0;
            }
            frac >>= 1;
            sprintf(buf, "C:%u, B:%d, T:%c%d.%02d", sampleCount++,
                batt,
                sign, whole, frac);
#if defined(USE_SERIAL)
            Serial.println(buf);
#endif
#if defined(USE_RFM69) 
            if (enableRadio)
                radio.sendWithRetry(GatewayNodeId, buf, strlen(buf));
#endif
        }
#endif
#if defined(USE_HIH6130) || defined(USE_SI7021) || defined(USE_SHT41)
        {
            float humidity(0), temperature(0);
#if defined(USE_HIH6130)
            sensor0.begin();
            // read temperature data
            unsigned char stat = sensor0.GetReadings(humidity, temperature);
            sensor0.end();
            if (stat != 0)
            {
                SampledSinceSleep = false;
                Wire.end();
                return;
            }
#elif defined(USE_SI7021)
#if defined(USE_TMP102)
            // The temperature readout from the Si7021 only has about 1 degree F resolution
            // If a TMP102 or TMP175 is also installed and compiled, use its temperature
            temperature = tmp102.finishReadTempCx256() / 256.f;
#elif defined(USE_TMP175)
            temperature = tmp175.finishReadTempCx256() / 256.f;
#else
            si7021.startReadTemperature();
            temperature = si7021.readTemperature();
#endif
            si7021.startReadHumidity();
            humidity = si7021.readHumidity();
#elif (defined(USE_SHT41))
            temperature = sht41.finishReadTempCx256() / 256.f;
            humidity = sht41.humidityX256() / 256.f;
            if (humidity < 0)
                humidity = 0;
            if (humidity > 100.f)
                humidity = 100.f;
#endif

            char sign = '+';
            if (temperature < 0.f) {
                temperature = -temperature;
                if (temperature < MAX_VALID_TEMPERATURE_C)
                    sign = '-';
                else
                    sign = '<';
            }
            else if (temperature == 0.f)
                sign = ' ';
            else if (temperature >= MAX_VALID_TEMPERATURE_C)
                sign = '>';

            int whole = (int)temperature;
            int wholeRh = (int)humidity;

            sprintf(buf, "C:%u, B:%d, T:%c%d.%02d R:%d.%02d", sampleCount++,
                batt,
                sign, whole,
                (int)(100.f * (temperature - whole)),
                wholeRh,
                (int)(100.f * (humidity - wholeRh)));
#if defined(USE_SERIAL)
            Serial.println(buf);
#endif
#if defined(USE_RFM69) 
            if (enableRadio)
                radio.sendWithRetry(GatewayNodeId, buf, strlen(buf));
#endif
        }
#endif
        Wire.end();
    }

    if (now - TimeOfWakeup > ListenAfterTransmitMsec)
    {
        SleepTilNextSample();
        SampledSinceSleep = false;
        TimeOfWakeup = millis();
        ListenAfterTransmitMsec = NormalListenAfterTransmit;
#if defined(USE_TMP102)
        tmp102.startReadTemperature();
#endif
#if defined(USE_TMP175)
        tmp175.startReadTemperature();
#endif
#if defined(USE_SI7021)
#endif
#if defined(USE_SHT41)
        sht41.startReadTemperature();
#endif
    }
}

#if !defined(SLEEP_WITH_TIMER2)
void sleepPinInterrupt()	// requires RC parallel between two pins, depending on PCB rev
{
    detachInterrupt(digitalPinToInterrupt(TIMER_RC_PIN));
}
#else
ISR(TIMER2_OVF_vect) {} // do nothing but wake up
#endif

namespace {
    unsigned SleepTilNextSample()
    {
#if defined(USE_SERIAL)
        Serial.print("sleep for ");
        Serial.println(SleepLoopTimerCount);
        Serial.flush();
        Serial.end();// wait for finish and turn off pins before sleep
        pinMode(0, INPUT); // Arduino libraries have a symbolic definition for Serial pins?
        pinMode(1, INPUT);
#endif

#if defined(USE_RFM69) 
        if (enableRadio)
            radio.sleep();
#endif

#if defined(TELEMETER_BATTERY_V)
        auto savedADC = ADCSRA;
        ADCSRA = 0; // Turn off ADC. credit to https://gist.github.com/JChristensen/5616922
#endif

        // sleep mode power supply current measurements indicate this appears to be redundant
        power_all_disable(); // turn off everything

        unsigned count = 0;

#if !defined(SLEEP_WITH_TIMER2)
        // this requires external RC (e.g. 1uF and 10M) in parallel to trigger INT1 on pin 3
        while (count < SleepLoopTimerCount)
        {
            power_timer0_enable(); // delay() requires this
            // determined empirically using BatteryExtenderTest
            static const int TIMER_INIT_CHARGE_MSEC = 20; //AA cell internal resistance affects this
#if (TIMER_INIT_STYLE != TIMER_INIT_STYLE_REV06) 
            pinMode(TIMER_RC_PIN, OUTPUT);
            digitalWrite(TIMER_RC_PIN, HIGH);
            for (uint8_t i = 0; ; i++)
            {
                digitalWrite(TIMER_RC_GROUND_PIN, LOW);
                delay(TIMER_INIT_CHARGE_MSEC);
#if TIMER_INIT_STYLE >= TIMER_INIT_STYLE_REV07 // only the charge pump needs to be cycled
                if (i == D4PwmCount)
                    break;
                digitalWrite(TIMER_RC_GROUND_PIN, HIGH);
                delay(TIMER_INIT_CHARGE_MSEC);
#else
                break;
#endif
            }
#else
            pinMode(TIMER_RC_GROUND_PIN, OUTPUT);
            digitalWrite(TIMER_RC_GROUND_PIN, LOW);
            delay(TIMER_INIT_CHARGE_MSEC); // Charge the C
            pinMode(TIMER_RC_GROUND_PIN, INPUT);
#endif
            pinMode(TIMER_RC_PIN, INPUT);
            cli();
            power_timer0_disable(); // timer0 powered down again
            attachInterrupt(digitalPinToInterrupt(TIMER_RC_PIN), sleepPinInterrupt, LOW);
            set_sleep_mode(SLEEP_MODE_PWR_DOWN);
            sleep_enable();
            sleep_bod_disable();
            sei();
            sleep_cpu(); // Power supply measured: About 1 to 2 uA rising to about 300 uA as RC approaches Vdd/2 on REV05 and lower
            sleep_disable();
            sei();
            count += 1;
        }
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

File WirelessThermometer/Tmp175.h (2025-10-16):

#pragma once
// 2wire interface for TMP175 temperature sensor
class TMP175 {
public:
    TMP175(uint8_t addr, unsigned DelayMsec = SETTLE_TIME_MSEC) : SlaveAddress(addr), SettleTimeMsec(DelayMsec)
    {}

    void startReadTemperature()
    {
        Wire.beginTransmission(SlaveAddress);
        writePointerRegister(CONFIGURATION_REG);
        // R0 without R1 means 10 bit conversion (1/4 degree C) in 55msec
        // OS means one-shot
        // SD means shut down immediately after the one-shot conversion
        uint8_t config = OS | SD | R0;
        Wire.write(config);
        Wire.endTransmission(); 
        MsecWhenStartedTemperature = millis();
    }

    int16_t finishReadTempCx256()
    {
        long tmp175Delay = millis() - MsecWhenStartedTemperature;
        tmp175Delay = static_cast<long>(SettleTimeMsec) - tmp175Delay;
        if (tmp175Delay > 0)
            delay(tmp175Delay);

        Wire.beginTransmission(SlaveAddress);
        writePointerRegister(TEMPERATURE_REG);
        Wire.endTransmission(false);

        int16_t tempCtimes256 = 0;
        static const uint8_t READ_TEMPERATURE_BYTE_COUNT = 2;
        Wire.requestFrom(SlaveAddress, READ_TEMPERATURE_BYTE_COUNT);
        for (int i = 0; i < READ_TEMPERATURE_BYTE_COUNT; i++)
        {
            if (Wire.available())
            {
                unsigned char v = Wire.read();
                tempCtimes256 <<= 8;
                tempCtimes256 |= v;
            }
            else
                return 0x7FFF;
        }
        return tempCtimes256;
    }

    void delayForADC()
    {
        delay(SettleTimeMsec); // let temperature ADC settle--depends on R0/R1
    }

    int16_t readTempCx256()
    {
        startReadTemperature();
        delayForADC();
        return finishReadTempCx256();
    }
    void setup()
    {
        Wire.beginTransmission(SlaveAddress);
        writePointerRegister(CONFIGURATION_REG);
        uint8_t config = SD; // set shutdown mode to minimize battery drain
        Wire.write(config);
        Wire.endTransmission();
    }

    void dump()
    {
        for (int i = 0; i < NUM_POINTERS; i += 1)
        {
            Wire.beginTransmission(SlaveAddress);
            writePointerRegister(static_cast<Pointer_t>(i));
            Wire.endTransmission(false);
            Wire.requestFrom(SlaveAddress, static_cast<uint8_t>(2));
            Serial.print("Dump config="); 
            Serial.println(i);
            while (Wire.available())
            {
                Serial.print(" 0x"); 
                Serial.print((int)Wire.read(), HEX);
            }
            Serial.println();
        }
    }
private:
    enum {SETTLE_TIME_MSEC = 70 };
    const uint8_t SlaveAddress;
    enum Pointer_t { TEMPERATURE_REG, CONFIGURATION_REG, T_LOW_REG, T_HIGH_REG, NUM_POINTERS};
    enum Configuration_t {
        SD = 1, TM = 1 << 1, POL = 1 << 2,
        F0 = 1 << 3, F1 = 1 << 4,
        R0 = 1 << 5, R1 = 1 << 6, OS = 1 << 7
    };
    void writePointerRegister(Pointer_t pointerReg)
    { Wire.write(static_cast<uint8_t>(pointerReg)); }
    unsigned long MsecWhenStartedTemperature;
    const unsigned SettleTimeMsec;
};

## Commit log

2021-11-19 PCB rev1
2023-06-26 reversible power jack
2023-06-28 try si7021
    [Enclosure.cfg]
2023-07-05 as built
    [cover.stl]
2025-01-08 flag temperature out of bounds
2025-04-24 weather tight
    [Enclosure.cfg]
2025-05-07 beefier weather tight
    [Enclosure.cfg]
2025-05-12 oops. Only center hole for AA cell is clear on back side
    [Enclosure.cfg]
2025-06-01 schmidtt trigger
    [pcb.sch]
2025-06-01 pcb update
    [pcb.sch]
2025-06-03 so-23-5 outline
    [pcb.sch]
2025-06-03 sketch support for schmitt trigger PCB
2025-06-09 gerber files
2025-06-11 sketch matches latest PCB
2025-06-21 as printed
    [Enclosure.cfg]
2025-06-30 base no exterior screw holes
    [Enclosure.cfg]
2025-06-30 interior nut clearance
2025-08-01 weather-tight enclosure
    [Enclosure.cfg]
2025-08-01 REV 07 of PCB
2025-08-05 LTSpice simulated battery saver
    [pcb.sch]
2025-08-05 Battery Extender
2025-08-06 Spice model for diodes
2025-08-07 match pcb
2025-08-09 prettier circuit diagram
2025-08-19 pcb snapshot
2025-08-20 flex mount double AA holder
2025-08-20 ordered pcb
2025-08-27 test REV08 PCB
2025-10-09 rev 16. ADC restart was not
2026-02-25 pcb 9 both schmitt trigger and battery extender
    [pcb.sch, power supply current during RC decay.ods]
2026-02-25 Update README with clearer Arduino usage instructions
    Clarified instructions for using a 5V Arduino in the assembly process.
2026-02-27 RC graph
    [power supply current during RC decay.ods]

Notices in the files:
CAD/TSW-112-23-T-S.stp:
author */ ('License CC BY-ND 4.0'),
